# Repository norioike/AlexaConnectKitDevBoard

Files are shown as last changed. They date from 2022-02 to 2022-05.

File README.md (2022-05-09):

# AlexaConnectKit Dev-Boardについて
この基板は主にAlexa Connect Kitを使ったデバイスを開発するための開発ボードとして作りました。
RP2040をMCUにAlexaConnectKitのモジュール "ESP32-PICO-V3-ZERO"と通信ができるようになっています。
またRP2040のGPIOは出せるだけ出しているので、センサー類を追加したり駆動系を追加する事でオリジナルのAlexa対応ロボットなどが作れるようになる（と思います)

ただ、この基板単体でも遊べるようにタクトスイッチとフルカラーLEDを実装しています。
しかし、私のミスでフルカラーLEDは点灯しません。電源は5Vにもかかわらず、3.3Vを供給。そのため命令を送っても点灯しません。

部品が余ったので数個だけ頒布しています。
もしよろしければこちらをご覧下さい。

https://www.switch-science.com/catalog/8078/

## Alexa Connect Kitについて
ハードウェアにAlexaを簡単に統合できるようにするためのマネージメントサービスで、これを使うことでAlexaに話しかけるとハードウェアを動かしたり、
逆にセンサー情報をAlexaに送る事ができるハードウェアを簡単に開発する事ができるようになります。
具体的にAlexa内蔵の電子レンジみたいなものを作ることも可能です。

システムの構成は、従来ハードウェアにAlexaと通信ができるモジュールを搭載することで実現できるようになっています。こうすることで開発負荷を下げることを想定しているのだと思います。
今回はESP32-PICO-V3-ZEROがそのモジュールで、この中にAlexaと通信するために必要なファームウェアが書かれており、開発者がこのモジュールとUARTなどで通信できるようにハードウェアを開発すればOKです。
すべての制御は自身が実装したMCUに書くことになります。ここでAlexaに対して命令を送ったり、受け取ったりできるようにすることでAlexa対応のオリジナルデバイスが実現できます。

## セットアップについて
セットアップはWikiにまとめています。このセットアップが完了できれば、あとは自由に開発するだけの状態になります。

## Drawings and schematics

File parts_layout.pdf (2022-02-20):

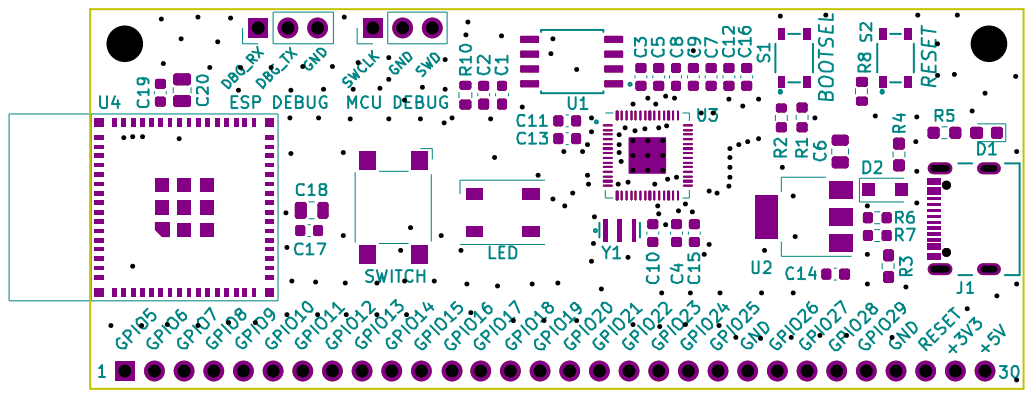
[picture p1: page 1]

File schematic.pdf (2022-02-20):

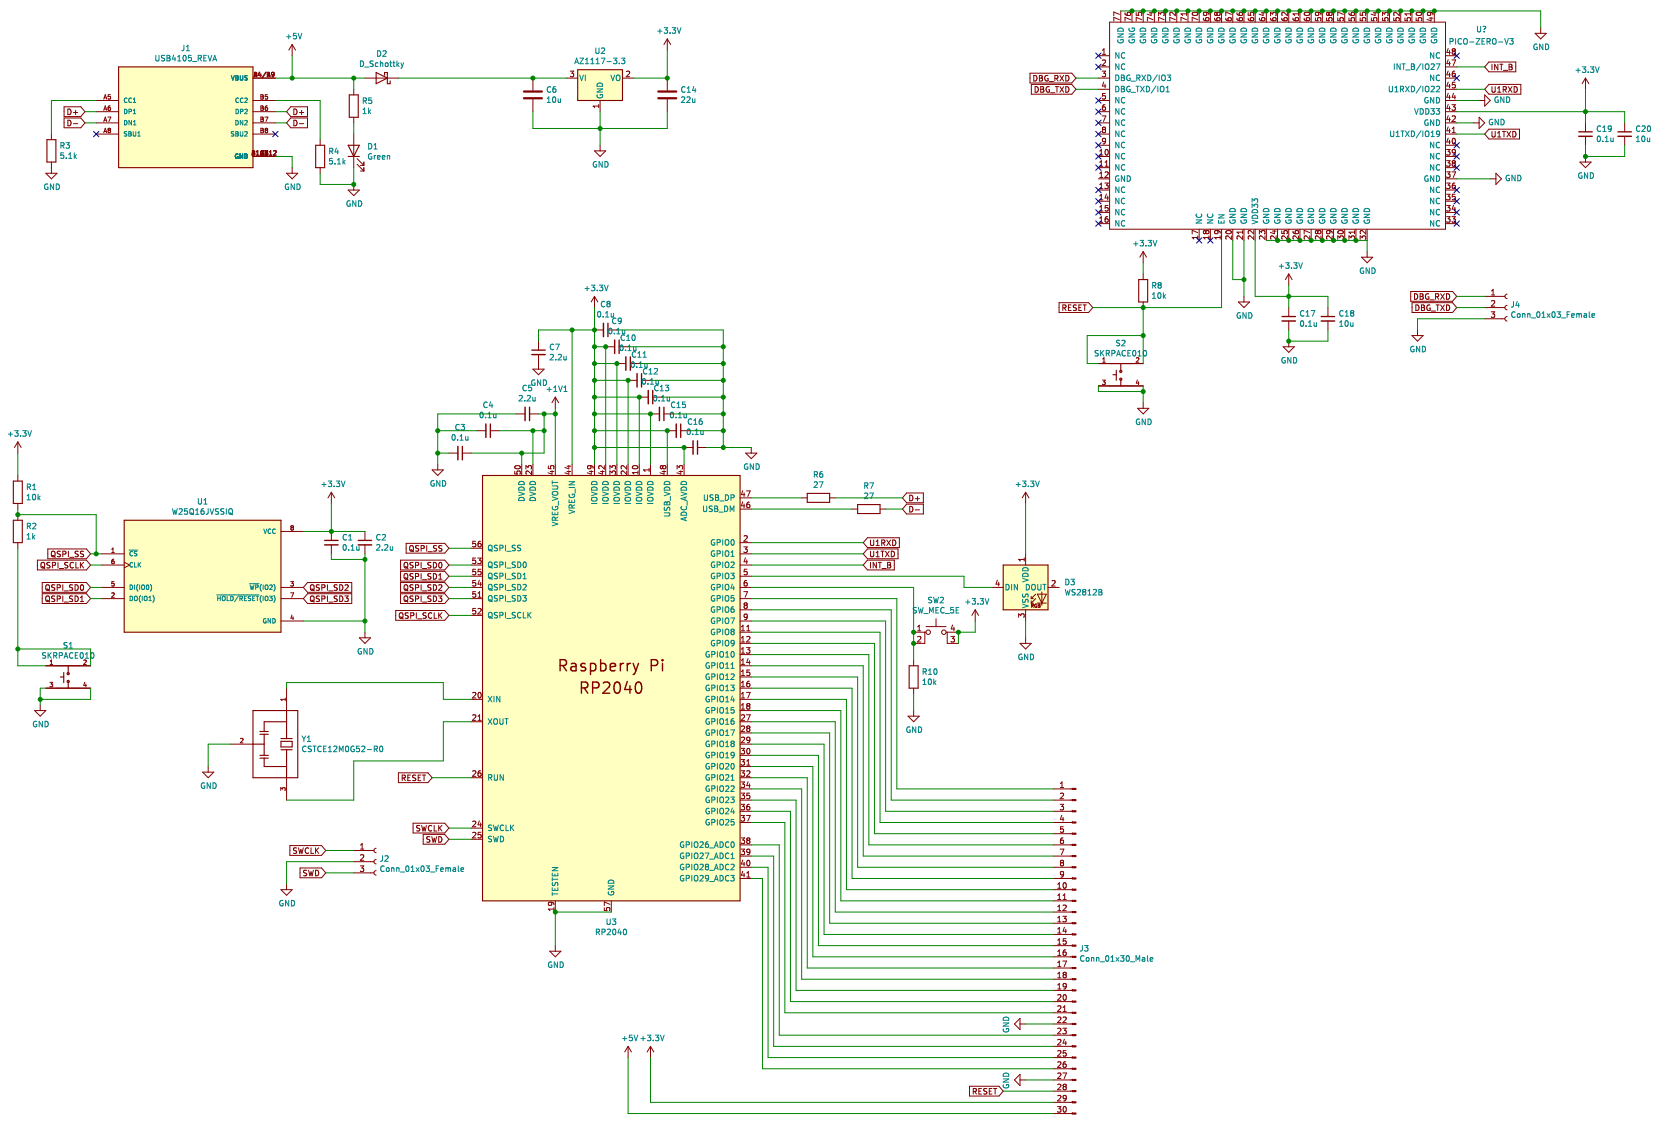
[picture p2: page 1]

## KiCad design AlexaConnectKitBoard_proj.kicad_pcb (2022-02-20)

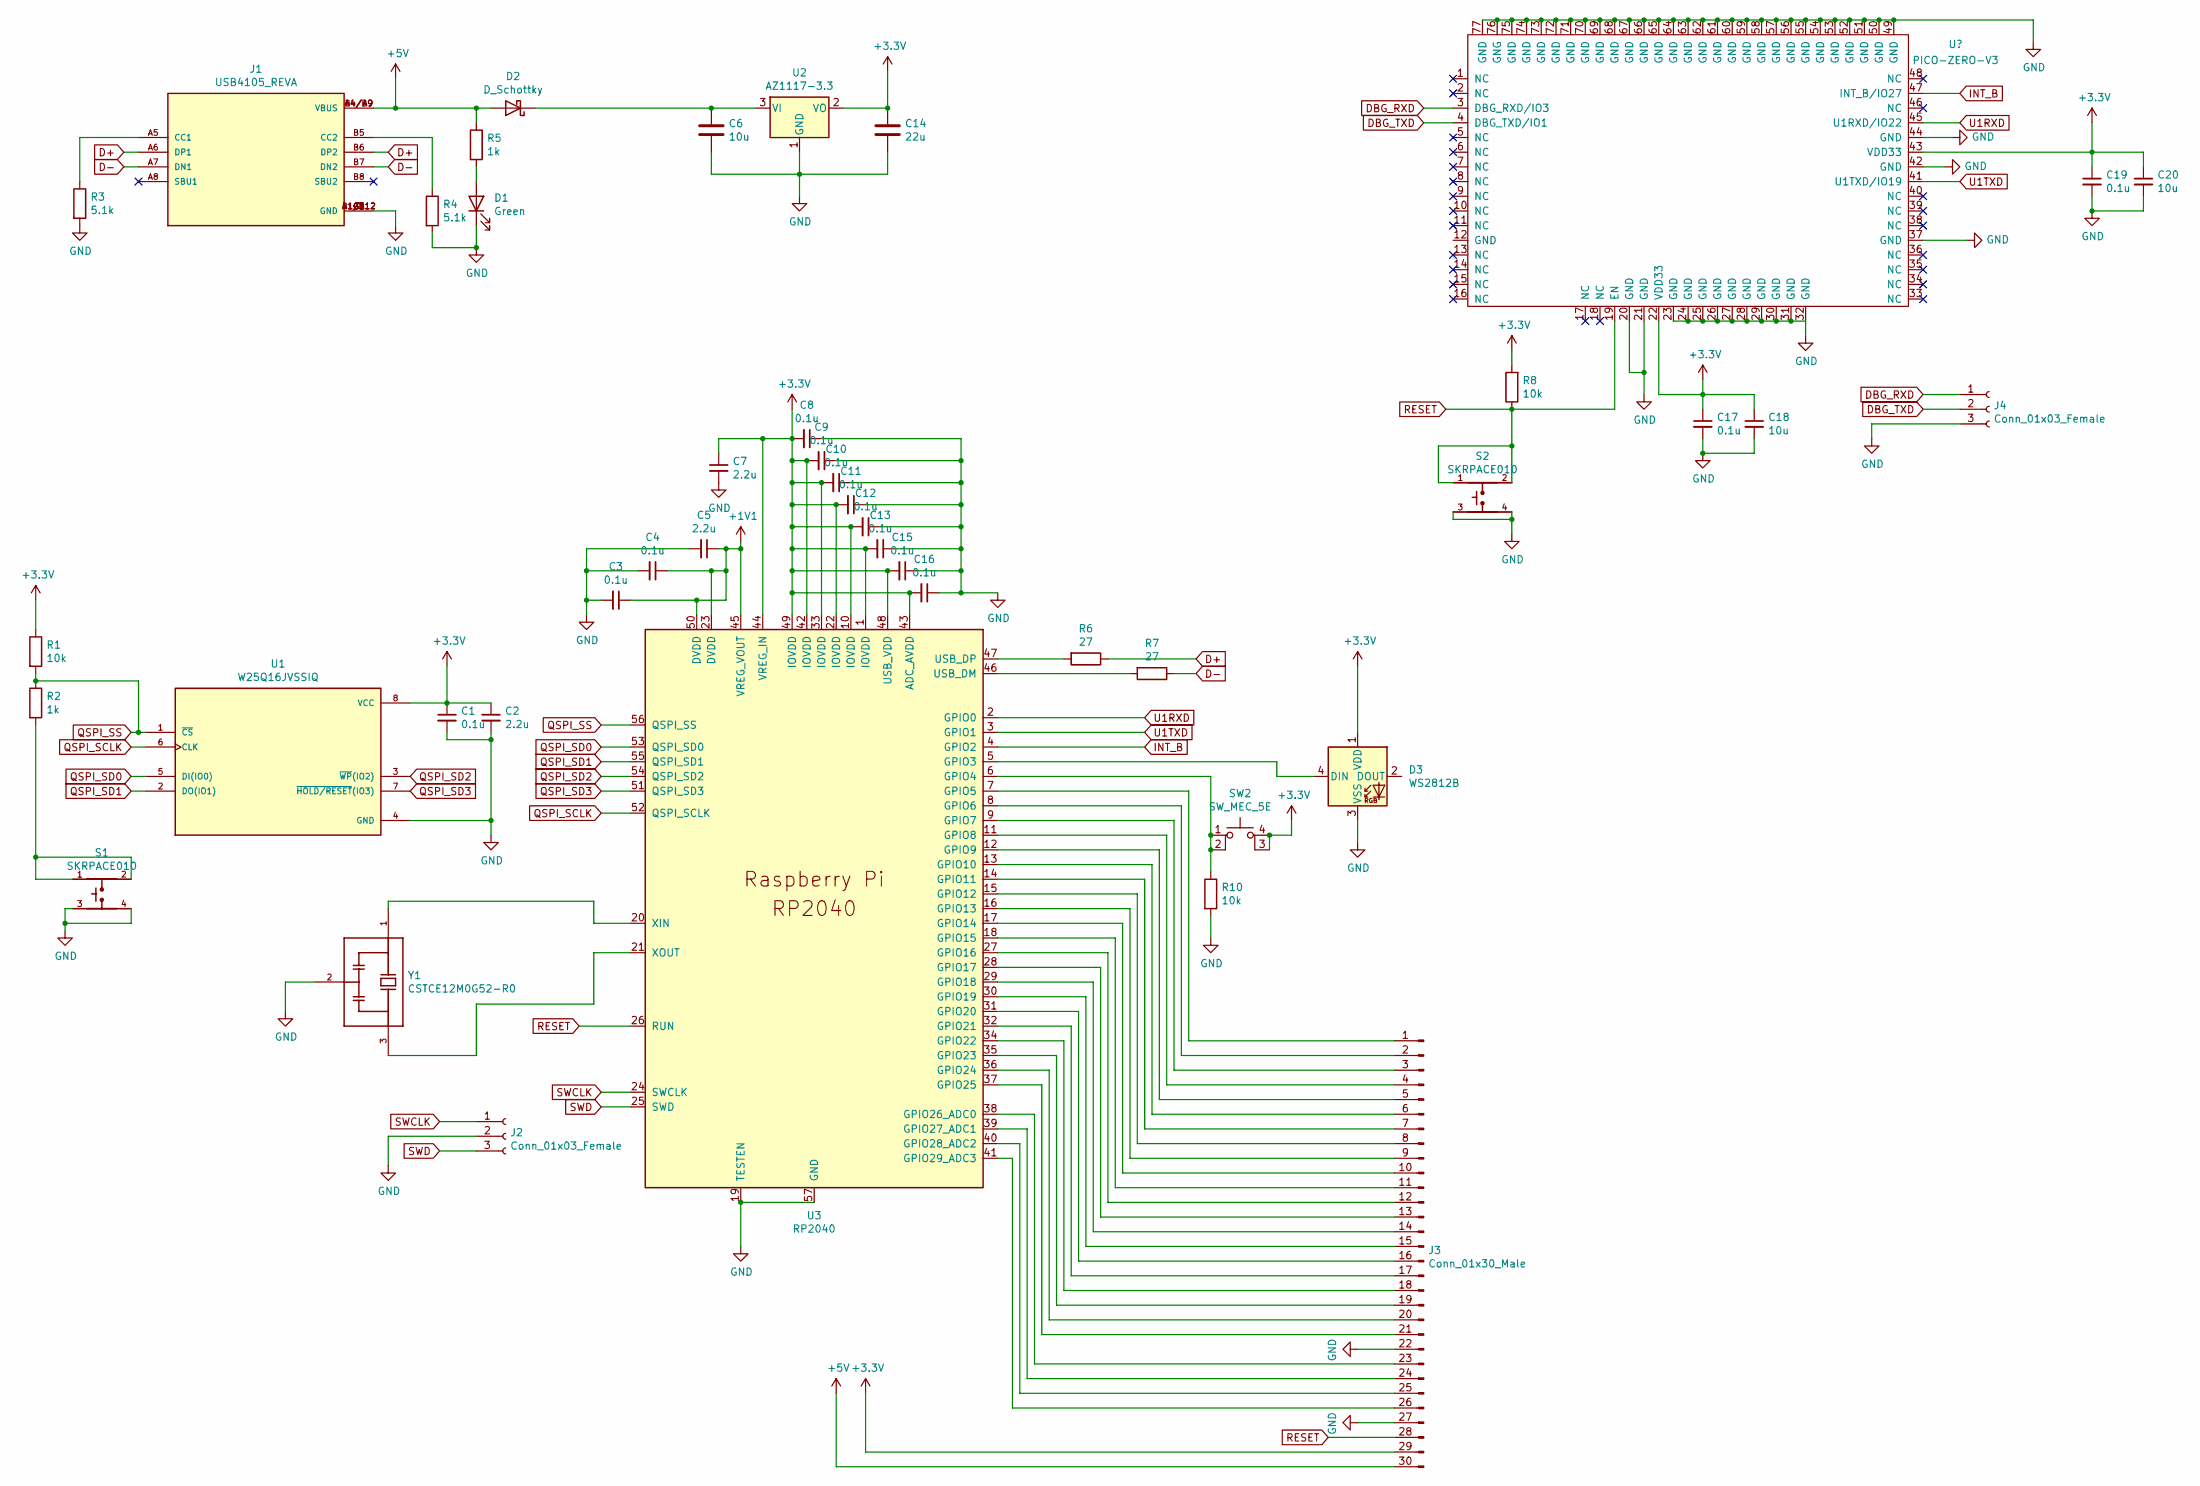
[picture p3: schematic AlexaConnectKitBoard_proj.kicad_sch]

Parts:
C1, C3, C4, C8, C9, C10, C11, C12, C13, C15, C16, C17, C19: 0.1u; C_0603_1608Metric
C2, C5, C7: 2.2u; C_0603_1608Metric
C6, C18, C20: 10u; C_0805_2012Metric
C14: 22u; C_0603_1608Metric
D1: Green; LED_0603_1608Metric_Pad1.05x0.95mm_HandSolder
D2: D_Schottky; D_SOD-123F
D3: WS2812B; LED_WS2812B_PLCC4_5.0x5.0mm_P3.2mm
J1: USB4105_REVA; GCT_USB4105_REVA; PARTREV 0.2
J2, J4: Conn_01x03_Female; PinHeader_1x03_P2.54mm_Vertical
J3: Conn_01x30_Male; PinHeader_1x30_P2.54mm_Vertical
R1, R8, R10: 10k; R_0603_1608Metric
R2: 1k; R_0603_1608Metric
R3, R4: 5.1k; R_0603_1608Metric_Pad0.98x0.95mm_HandSolder
R5: 1k; R_0603_1608Metric_Pad0.98x0.95mm_HandSolder
R6, R7: 27; R_0603_1608Metric
S1, S2: SKRPACE010; SW_SKRPACE010
SW2: SW_MEC_5E; SW_SPST_Omron_B3FS-105xP
U1: W25Q16JVSSIQ; SOIC127P790X216-8N
U2: AZ1117-3.3; SOT-223-3_TabPin2
U3: RP2040; RP2040-QFN-56
Y1: CSTCE12M0G52-R0; OSC_CSTCE12M0G52-R0; PARTREV May 7, 2019

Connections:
+1V1: C3.1, C4.1, C5.1, U3.23 (DVDD), U3.45 (VREG_VOUT), U3.50 (DVDD)
+3V3: C1.1, C2.1, C7.1, C8.2, C9.2, C10.2, C11.2, C12.2, C13.2, C14.1, C15.2, C16.2, C17.1, C18.1, C19.1, C20.1, D3.1 (VDD), J3.29, R1.1, R8.2, SW2.3 (K), SW2.4 (A), U1.8 (VCC), U2.2 (VO), U3.1 (IOVDD), U3.10 (IOVDD), U3.22 (IOVDD), U3.33 (IOVDD), U3.42 (IOVDD), U3.43 (ADC_AVDD), U3.44 (VREG_IN), U3.48 (USB_VDD), U3.49 (IOVDD); also elsewhere on the board
+5V: D2.2 (A), J1.A4/B9 (VBUS), J1.B4/A9 (VBUS), J3.30, R5.1
D+: J1.A6 (DP1), J1.B6 (DP2), R6.1
D-: J1.A7 (DN1), J1.B7 (DN2), R7.1
DBG_RXD: J4.1; also elsewhere on the board
DBG_TXD: J4.2; also elsewhere on the board
GND: C1.2, C2.2, C3.2, C4.2, C5.2, C6.2, C7.2, C8.1, C9.1, C10.1, C11.1, C12.1, C13.1, C14.2, C15.1, C16.1, C17.2, C18.2, C19.2, C20.2, D1.1 (K), D3.3 (VSS), J1.A1/B12 (GND), J1.B1/A12 (GND), J1.G1 (GND), J1.G2 (GND), J1.G3 (GND), J1.G4 (GND), J2.2, J3.22, J3.27, J4.3, R3.2, R4.2, R10.2, S1.3, S1.4, S2.3, S2.4, U1.4 (GND), U2.1 (GND), U3.19 (TESTEN), U3.57 (GND), Y1.2; also elsewhere on the board
INT_B: U3.4 (GPIO2); also elsewhere on the board
unnamed: C6.1, D2.1 (K), U2.3 (VI)
unnamed: D1.2 (A), R5.2
unnamed 11: D3.4 (DIN), U3.5 (GPIO3); also elsewhere on the board
unnamed: J1.A5 (CC1), R3.1
unnamed: J1.B5 (CC2), R4.1
unnamed: J3.1, U3.7 (GPIO5)
unnamed: J3.2, U3.8 (GPIO6)
unnamed: J3.3, U3.9 (GPIO7)
unnamed: J3.4, U3.11 (GPIO8)
unnamed: J3.5, U3.12 (GPIO9)
unnamed: J3.6, U3.13 (GPIO10)
unnamed: J3.7, U3.14 (GPIO11)
unnamed: J3.8, U3.15 (GPIO12)
unnamed: J3.9, U3.16 (GPIO13)
unnamed: J3.10, U3.17 (GPIO14)
unnamed: J3.11, U3.18 (GPIO15)
unnamed: J3.12, U3.27 (GPIO16)
unnamed: J3.13, U3.28 (GPIO17)
unnamed: J3.14, U3.29 (GPIO18)
unnamed: J3.15, U3.30 (GPIO19)
unnamed: J3.16, U3.31 (GPIO20)
unnamed: J3.17, U3.32 (GPIO21)
unnamed: J3.18, U3.34 (GPIO22)
unnamed: J3.19, U3.35 (GPIO23)
unnamed: J3.20, U3.36 (GPIO24)
unnamed: J3.21, U3.37 (GPIO25)
unnamed: J3.23, U3.38 (GPIO26_ADC0)
unnamed: J3.24, U3.39 (GPIO27_ADC1)
unnamed: J3.25, U3.40 (GPIO28_ADC2)
unnamed: J3.26, U3.41 (GPIO29_ADC3)
unnamed: R2.2, S1.1, S1.2
unnamed: R6.2, U3.47 (USB_DP)
unnamed: R7.2, U3.46 (USB_DM)
unnamed 42: R10.1, SW2.1, SW2.2, U3.6 (GPIO4); also elsewhere on the board
unnamed: U3.20 (XIN), Y1.1
unnamed: U3.21 (XOUT), Y1.3
QSPI_SCLK: U1.6 (CLK), U3.52 (QSPI_SCLK)
QSPI_SD0: U1.5 (DI(IO0)), U3.53 (QSPI_SD0)
QSPI_SD1: U1.2 (DO(IO1)), U3.55 (QSPI_SD1)
QSPI_SD2: U1.3 (~WP(IO2)), U3.54 (QSPI_SD2)
QSPI_SD3: U1.7 (~HOLD/RESET(IO3)), U3.51 (QSPI_SD3)
QSPI_SS: R1.2, R2.1, U1.1 (~CS), U3.56 (QSPI_SS)
RESET: J3.28, R8.1, S2.1, S2.2, U3.26 (RUN); also elsewhere on the board
SWCLK: J2.1, U3.24 (SWCLK)
SWD: J2.3, U3.25 (SWD)
U1RXD: U3.2 (GPIO0); also elsewhere on the board
U1TXD: U3.3 (GPIO1); also elsewhere on the board

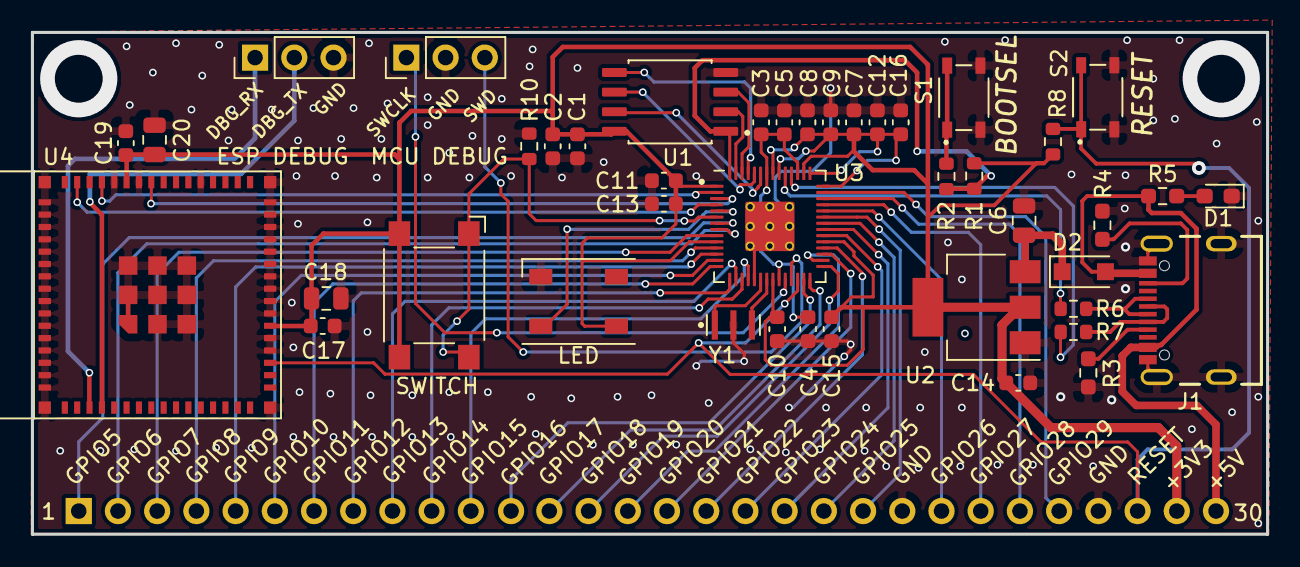
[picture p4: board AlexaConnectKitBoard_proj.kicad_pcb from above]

Board: 2 copper layers, 80.0 x 32.5 mm, 44 parts (0 on the bottom side), 56 nets.

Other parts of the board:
LED: WS2812B; LED_WS2812B_PLCC4_5.0x5.0mm_P3.2mm
SWITCH: SW_MEC_5E; SW_SPST_Omron_B3FS-105xP
U4: PICO-ZERO-V3; PICO-V3-ZERO

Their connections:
+3V3: LED.1, SWITCH.3, SWITCH.4, U4.22, U4.43; also elsewhere on the board
DBG_RXD: U4.3; also elsewhere on the board
DBG_TXD: U4.4; also elsewhere on the board
GND: LED.3, U4.20, U4.21, U4.23, U4.24, U4.25, U4.26, U4.27, U4.28, U4.29, U4.30, U4.31, U4.32, U4.37, U4.42, U4.44, U4.49, U4.50, U4.51, U4.52, U4.53, U4.54, U4.55, U4.56, U4.57, U4.58, U4.59, U4.60, U4.61, U4.62, U4.63, U4.64, U4.65, U4.66, U4.67, U4.68, U4.69, U4.70, U4.71, U4.72, U4.73, U4.74, U4.75, U4.76, U4.77; also elsewhere on the board
INT_B: U4.47; also elsewhere on the board
unnamed 11: LED.4; also elsewhere on the board
unnamed 42: SWITCH.1, SWITCH.2; also elsewhere on the board
RESET: U4.19; also elsewhere on the board
U1RXD: U4.45; also elsewhere on the board
U1TXD: U4.41; also elsewhere on the board
